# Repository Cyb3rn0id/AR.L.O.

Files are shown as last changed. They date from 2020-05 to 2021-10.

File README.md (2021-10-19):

This Repository is Archived since has been Replaced by the updated project [ARLOK](https://www.github.com/settorezero/arlok)

  

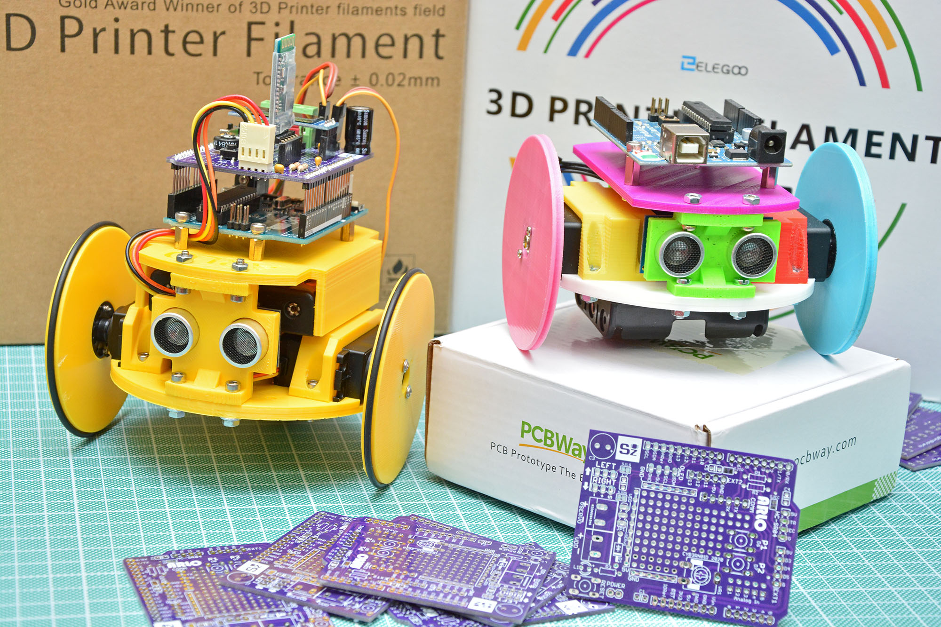
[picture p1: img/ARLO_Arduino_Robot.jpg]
ARLO - Arduino 3D printed Robot
  

# AR.L.O.
AR.L.O. Stands for ARduino Loaded with O-rings! It's an educational Arduino-based robot with a chassis printed in 3D. It features an ultrasonic range finder SR-HC04, an 0.91" OLED display, an HC-05 or HC-06 Bluetooth Module and two modified Servos (MG996R) for moving around.  I provided full-assembly instructions on my blog (see link at the end of this readme). Here you can find the STL to be printed and a source code.  Source code uses interrupts for make robot movement more efficient.

### PCBs by PCBWay
You can support my work by subscribing to PCBWay [using my invite link](https://www.pcbway.com/setinvite.aspx?inviteid=355653&from=settorezero2020) and then making AR.L.O. PCBs on PCBWay:   
PCB from PCBWay (https://www.pcbway.com/project/shareproject/ARLO___Arduino_3D_printed_Robot.html?from=settorezero2020)

### Links
- [Full Instructions](https://www.settorezero.com/wordpress/arlo)
- [BOM (Google Spreadheet with links)](https://docs.google.com/spreadsheets/d/1MPQHllO7yKMDYPbDrZOl-8qmw7OP9y3tJf0Bnw-yMyg/)
- [AR.L.O. video teaser](https://www.youtube.com/watch?v=O_3CUWvaW3k)
- [Video about AR.L.O. (only for italian users)](https://www.youtube.com/watch?v=JS_QYEIMfNo)
- [Video showing AR.L.O. setup](https://youtu.be/i7roltk-IzI)
- [AR.L.O. parts on Thingiverse](https://www.thingiverse.com/thing:4484651)
- [Servo Wheel by Obijuan](https://www.thingiverse.com/thing:19940)
- [Support my work by subscribing to PCBWay using my invite link](https://www.pcbway.com/setinvite.aspx?inviteid=355653&from=settorezero2020)
- [Support my work buying parts on Futura Elettronica after you've clicked on this link](https://www.futurashop.it/?tracking=5f004a6ba8be7)

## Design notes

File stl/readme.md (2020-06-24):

STL files for 3D printing.  
I've designed parts using [Tinkercad](https://www.tinkercad.com/).  

### Plate Base
I've added two plate bases which have different cavity for the servo: one large 40.6mm and the other large 41.2mm. Normally, standard servos are large 40mm, so the first one, 40.6mm. is suitable for servos like the Hi-tech that respect measures (consider also tolerances from 3D-Printer). I've found that some other servos, such as the XQPower I use, are slightly larger (about 40.8mm) and can't fit in the previous cavity, so I made a new cavity of 41.2mm and now the XQPower ones fits perfectly. So measure your servo width first than print. In case of doubt, print the 41.2mm.
  
### Wheels  
Wheels are generated with [Openscad](https://www.openscad.org/) using [Obijuan script](https://www.thingiverse.com/thing:19940) "Servo Wheel" on Thingiverse. You can found the script also on his [Github Repo for Miniskybot](https://github.com/Obijuan/Miniskybot/)

### Models
Arduino model, used for sizing and holes, is from [cmspooner on Thingiverse](https://www.openscad.org/)

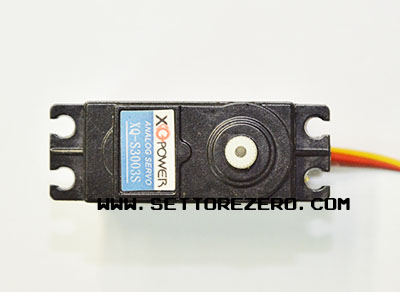
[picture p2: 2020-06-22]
img/arlo_servomotor.jpg

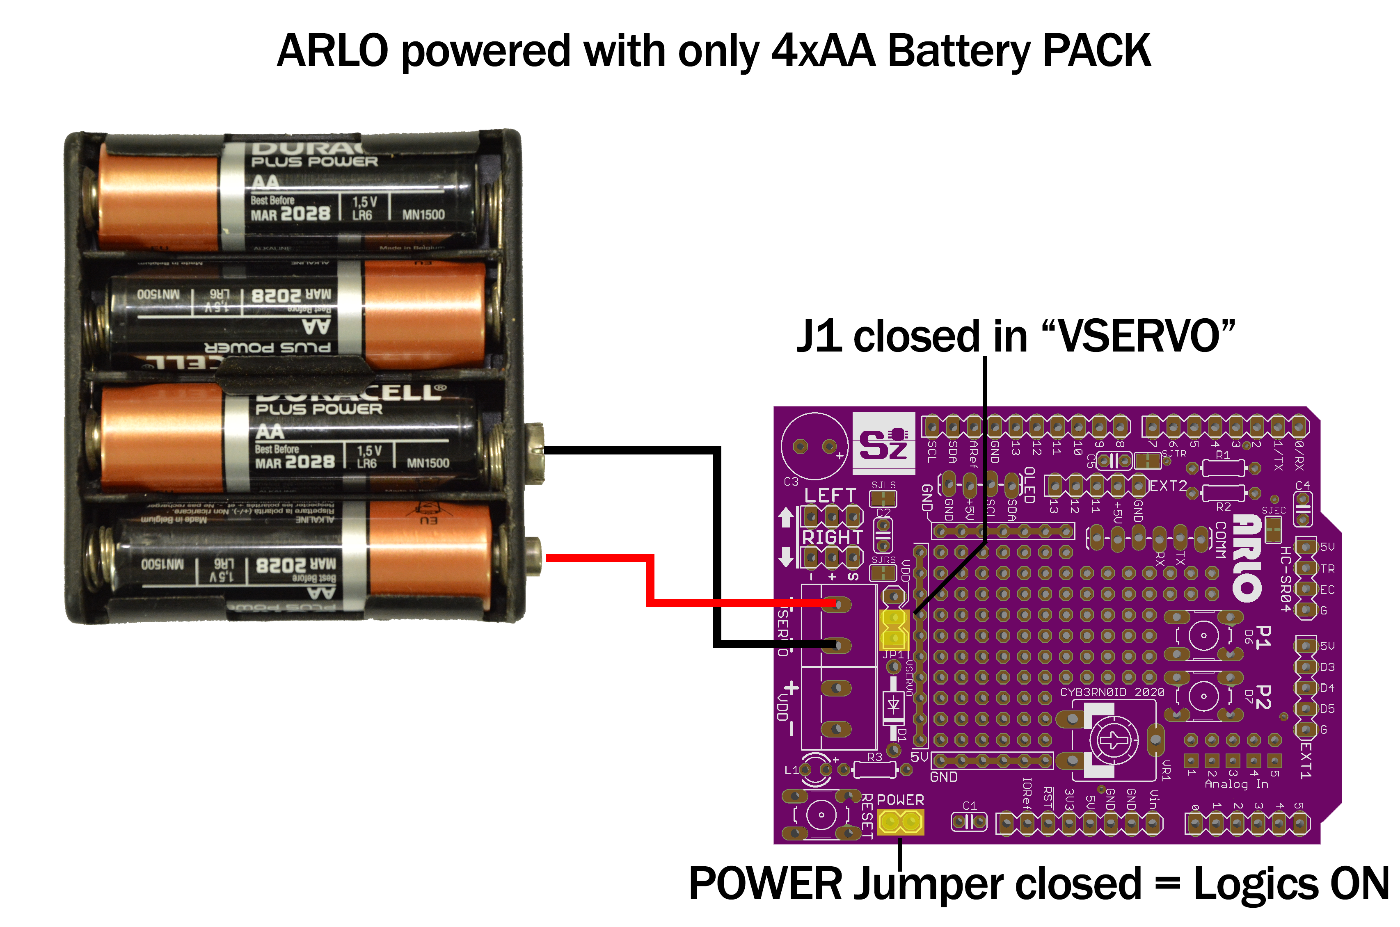
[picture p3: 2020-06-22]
img/arlo_shield_power_only6V.png

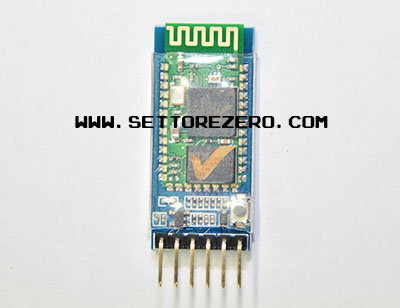
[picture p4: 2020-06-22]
img/arlo_bluetooth_module.jpg

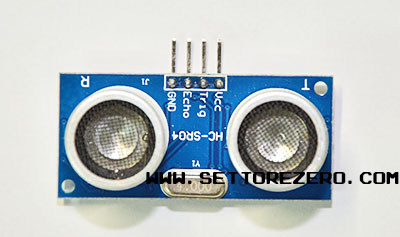
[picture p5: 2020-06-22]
img/arlo_ultrasonic_sensor.jpg

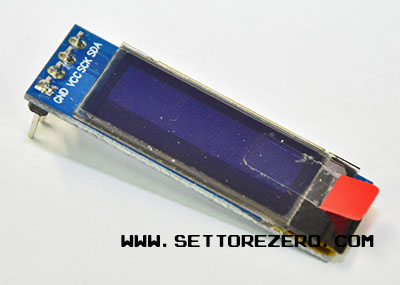
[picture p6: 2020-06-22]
img/arlo_oled_display.jpg

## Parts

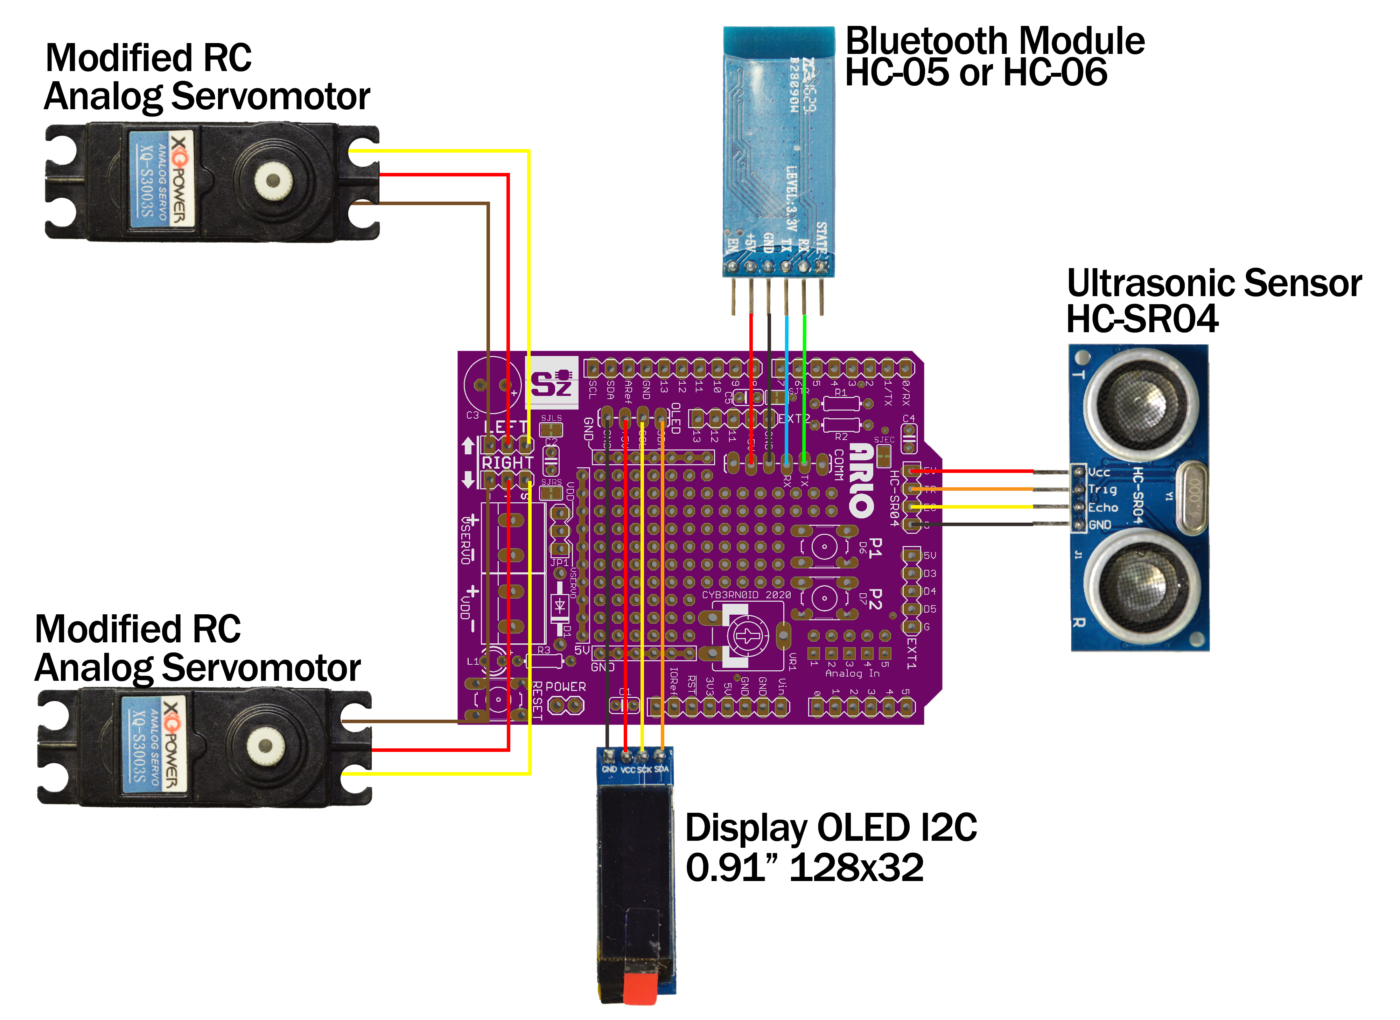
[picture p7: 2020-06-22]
img/arlo_shield_external_components.png

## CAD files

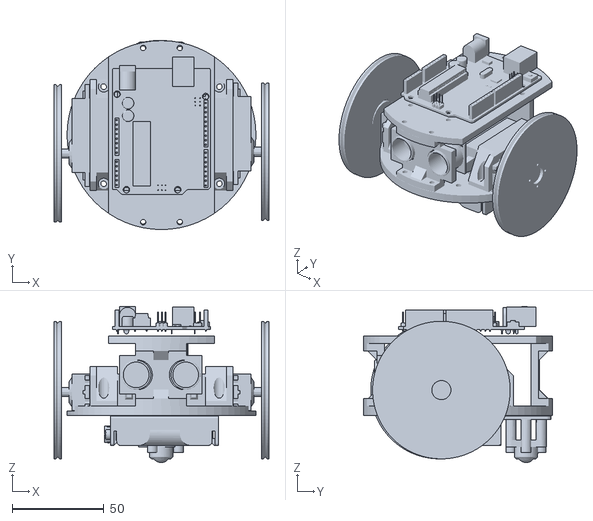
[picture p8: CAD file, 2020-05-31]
img/arlecchino_assembly.stl
117.2 x 103.1 x 85.1

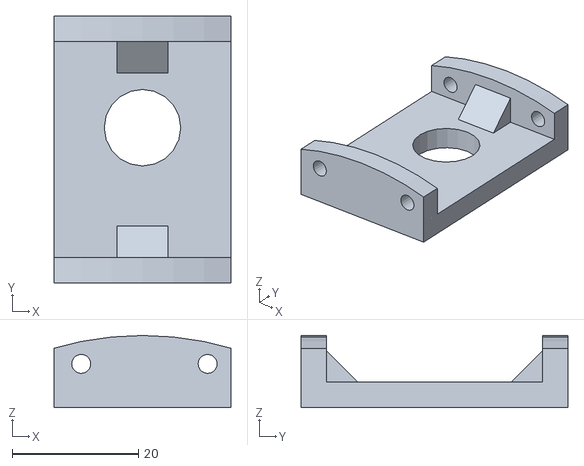
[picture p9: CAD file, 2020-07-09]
stl/pillar_hole_12mm.stl
28.0 x 42.2 x 11.4

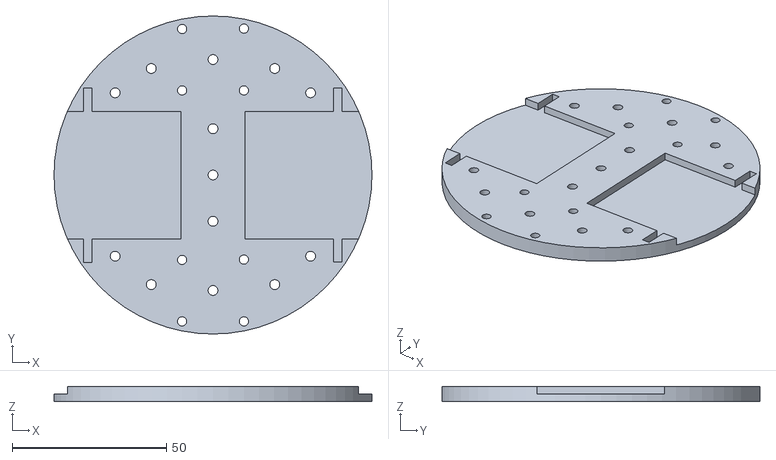
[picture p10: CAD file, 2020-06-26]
stl/plate_base.stl
103.0 x 103.0 x 5.00

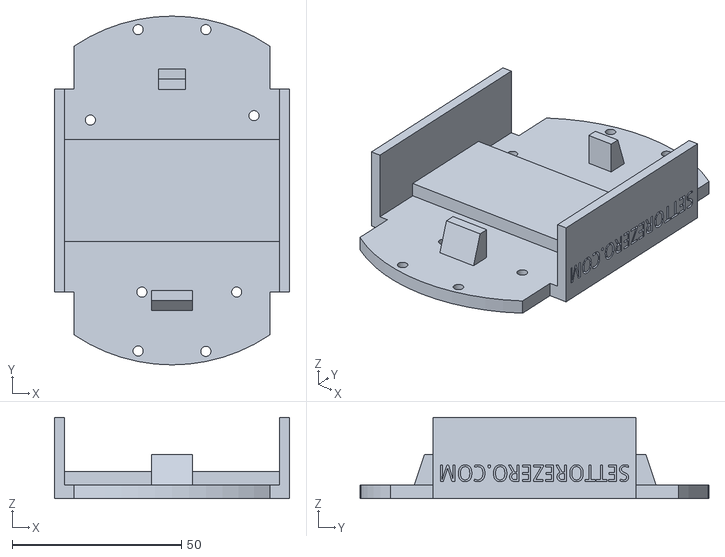
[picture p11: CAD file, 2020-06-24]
stl/plate_top.stl
69.4 x 103.0 x 24.0

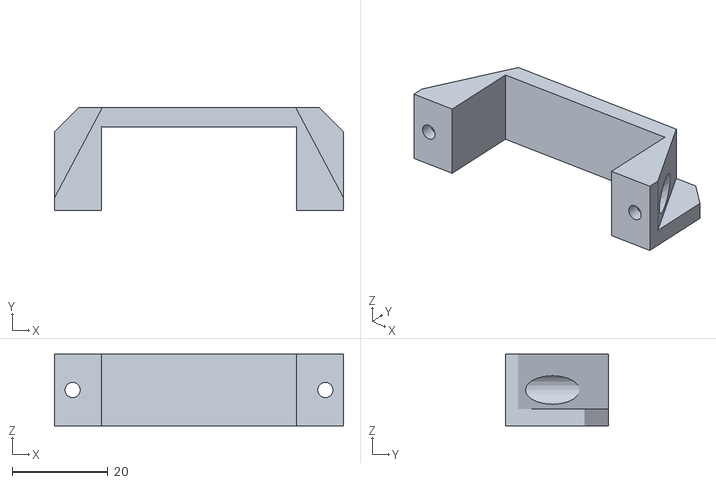
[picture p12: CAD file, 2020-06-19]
stl/servo_bracket.stl
60.5 x 21.5 x 15.0

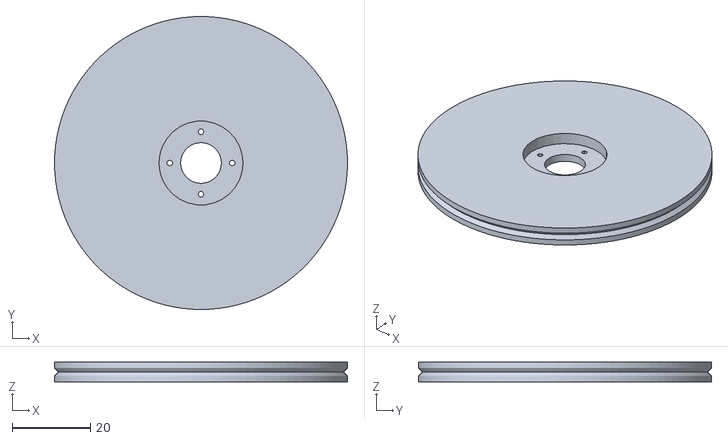
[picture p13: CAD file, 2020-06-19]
stl/my_servo-wheel.stl
75.0 x 75.0 x 5.00

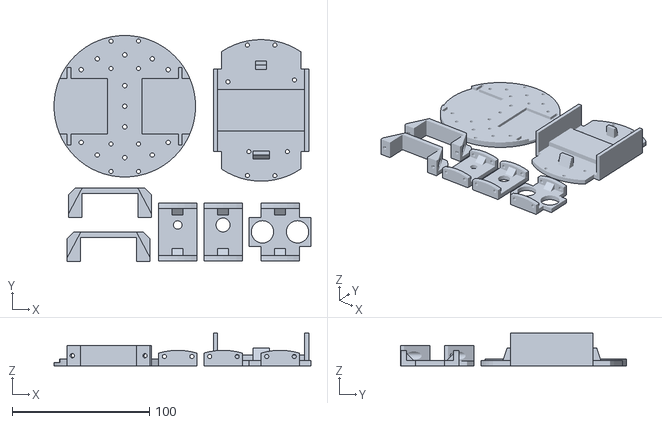
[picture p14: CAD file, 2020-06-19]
stl/all_but_wheels.stl
187.0 x 164.5 x 24.0

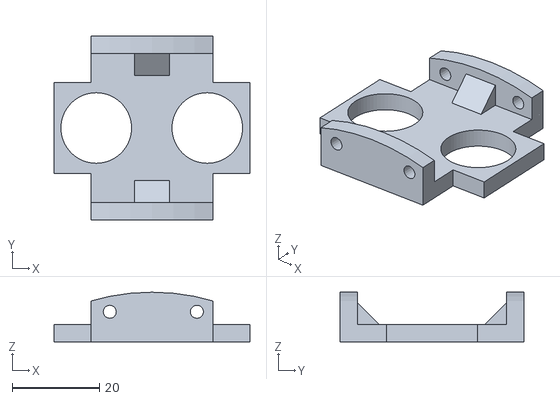
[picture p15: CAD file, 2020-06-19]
stl/pillar_HC-SR04.stl
45.0 x 42.2 x 11.4

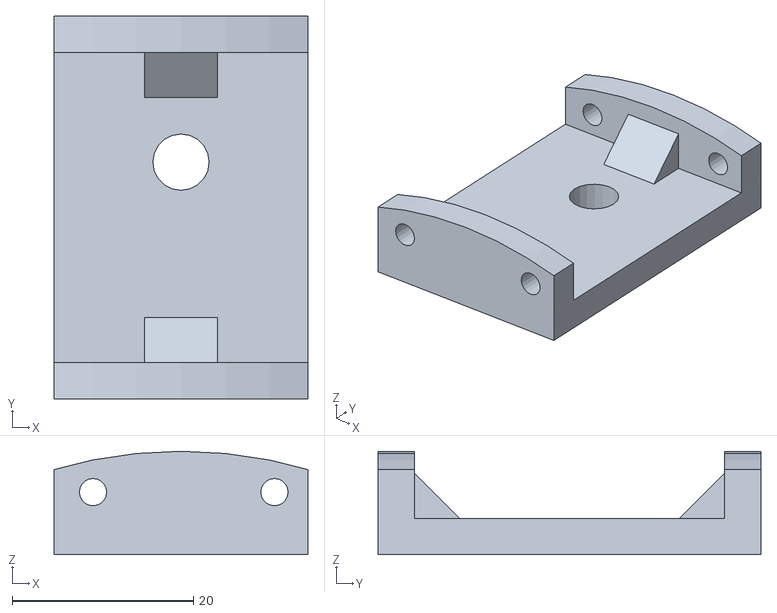
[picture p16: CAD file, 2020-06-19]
stl/pillar_hole_6mm.stl
28.0 x 42.2 x 11.4

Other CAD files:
stl/pillar_hole_10mm.stl

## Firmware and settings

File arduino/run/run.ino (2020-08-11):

/*
 * AR.L.O.
 * ARduino Loaded with Orings!
 * Educational Robot based on Arduino UNO
 * (c)2020 Giovanni Bernardo (https://www.settorezero.com)
 * 
 * https://www.github.com/CyB3rn0id/ar.l.o.
 * https://www.settorezero.com/wordpress/arlo
 * 
 * WARNING
 * This example will not work on Arduino LEONARDO
 * since it hasn't the Timer2
 *
 * LICENSE
 * Attribution-NonCommercial-ShareAlike 4.0 International 
 * (CC BY-NC-SA 4.0)
 * 
 * This is a human-readable summary of (and not a substitute for) the license:
 * You are free to:
 * 
 * SHARE - copy and redistribute the material in any medium or format
 * ADAPT -  remix, transform, and build upon the material
 * The licensor cannot revoke these freedoms as long as you follow the license terms.
 * Under the following terms:
 * ATTRIBUTION -  You must give appropriate credit, provide a link to the license, 
 * and indicate if changes were made. You may do so in any reasonable manner, 
 * but not in any way that suggests the licensor endorses you or your use.
 * NON COMMERCIAL -  You may not use the material for commercial purposes.
 * SHARE ALIKE -  If you remix, transform, or build upon the material,
 * you must distribute your contributions under the same license as the original.
 * NO ADDITIONAL RESTRICTIONS - You may not apply legal terms or technological 
 * measures that legally restrict others from doing anything the license permits.
 * 
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
 * Please read the Full License text at the following link:
 * https://creativecommons.org/licenses/by-nc-sa/4.0/legalcode
 *  
 * CREDITS
 * 
 * Steve Garrat
 * For the idea about using HC-SR04 sonar on interrupts:
 * (https://homediyelectronics.com/projects/arduino/arduinoprogramminghcsr04withinterrupts/)
 * 
 * Nick Bontranger
 * For the library allows using servo on Timer 2
 * https://github.com/nabontra/ServoTimer2
 * 
 * Adafruit
 * Because makes a lot of useful libraries
 * 
 * LIBRARIES TO BE INSTALLED
 * 
 * - Adafruit SSD1306 by Adafruit
 * - Adafruit GFX by Adafruit
 * - TimerOne by Jesse Tane, Jérôme Despatis, Michael Polli, Dan Clemens, Paul Stoffregen
 * 
 * This one requires manual installation (copy the folder in Documents\Arduino\Libraries)
 * https://github.com/nabontra/ServoTimer2
 * 
 */

// Libraries for OLED display
#include <SPI.h>
#include <Wire.h>
#include <Adafruit_GFX.h>
#include <Adafruit_SSD1306.h>
// Library for Timer1 Interrupts
#include <TimerOne.h>
// Library for using servo on Timer 2
#include <ServoTimer2.h>
// Library for Arduino internal eeprom memory
#include <EEPROM.h>

// Arduino used pins
#define MotorRPin 9       // signal for right servomotor
#define MotorLPin 10      // signal for left servomotor
#define P1 6              // pushbutton P1
#define P2 7              // pushbutton P2
#define trigPin 8         // HC-SR04 - trigger
#define echoPin 2         // HC-SR04 - echo

// stuff used by servomotors
ServoTimer2 MotorL;       // left servomotor object
ServoTimer2 MotorR;       // right servomotor object
uint16_t servoL_center=1500; // default value for left servomotor center point
uint16_t servoR_center=1500; // default value for right servomotor center point
uint8_t servoL_eeprom=0; // eeprom memory location for storing point zero of left servomotor
uint8_t servoR_eeprom=2; // eeprom memory location for storing point zero of right servomotor
#define SPEED  200 // normal speed for forward moving (center point+speed microseconds)
#define SPEED_SLOW 50 // speed used for maneuvers

// stuff used by sonar
#define TIMER_US 50 // Timer1 interrupt every 50uS
#define TICK_COUNTS 4500 // 4500*50uS = 225mS, time space between two consecutive trigger pulses
#define OBSTACLE 16 // AR.L.O. will stop if an obstacle is nearer than 16cm

// stuff used by oled display
#define SCREEN_WIDTH 128
#define SCREEN_HEIGHT 32
#define OLED_RESET -1
Adafruit_SSD1306 display(SCREEN_WIDTH, SCREEN_HEIGHT, &Wire, OLED_RESET);

// Global variables
volatile long distance=0; // distance measured by sonar, cm
// enum used for AR.L.O. working mode
enum arlo_mode
  {
  configuration,
  normal  
  };
arlo_mode mode=normal;// actual mode
// enum used for config menu pages on display
enum config_pages
  {
  left_motor=0,
  right_motor=1,
  config_end=2  
  };
  
void setup() 
  {
  // sonar setup
  pinMode(trigPin, OUTPUT);
  pinMode(echoPin, INPUT);
  // servomotors setup
  MotorL.attach(MotorLPin);   
  MotorR.attach(MotorRPin);
  // pushbuttons setup
  pinMode(P1,INPUT_PULLUP);
  pinMode(P2,INPUT_PULLUP);

  // interrupts
  Timer1.initialize(TIMER_US); // Initialise timer 1
  Timer1.attachInterrupt(timer1_ISR); // Attach interrupt to the timer service routine 
  attachInterrupt(digitalPinToInterrupt(echoPin), sonarEcho_ISR, CHANGE); // Attach interrupt to the sensor echo input
  
  delay(2000);
  Serial.begin(9600); // the HC-05 in normal mode (no AT) works ad 9600baud (38400 if in AT)
  
  randomSeed(analogRead(3)); // start-up random number generator using an unused analog input

  // SSD1306_SWITCHCAPVCC = generate display voltage from 3.3V internally
  if(!display.begin(SSD1306_SWITCHCAPVCC, 0x3C)) 
    { // Address 0x3C for 128x32
    Serial.println(F("SSD1306 allocation failed"));
    while(1); // Don't proceed, loop forever
    }
  display.clearDisplay();
  display.setTextSize(2);
  display.setTextColor(SSD1306_WHITE,SSD1306_BLACK);

  Serial.println("ARLO Startup");
  
  // center values used for servomotors, loaded from eeprom
  // if in the eeprom are saved values out of the range 500-2500, 1500 will be used
  // (this happens when eeprom memory was never used since contains 0xFFFF value)
  uint16_t LV=EEPROM.read(servoL_eeprom)<<8;
  LV|=EEPROM.read(servoL_eeprom+1);
  uint16_t RV=EEPROM.read(servoR_eeprom)<<8;
  RV|=EEPROM.read(servoR_eeprom+1);
  if (LV<2501 && LV>499) servoL_center=LV;
  if (RV<2501 && RV>499) servoR_center=RV;

  fermo(100);
  
  // if P1 is pressed during the setup function, I'll start the setup mode
  if (digitalRead(P1)==0) 
    {
      mode=configuration;
      while(digitalRead(P1)==0) {continue;}
      Serial.println("Setup mode");
    }
  }

void loop()
  {
  static boolean juststarted=true;
  while (mode==configuration) config_menu();

  display.setTextSize(2);
  display.setCursor(0,0);
  
  if (juststarted)
    {
    fermo(100);
    display.println("WAIT");
    display.display(); 
    fermo(2000); // servomotors stopped while sonar goes stable
    juststarted=false;  
    }
  display.println("ARLO RUN");
  if (distance>3000)
    {
    display.print("go ahead!");
    }
  else
    {
    display.print(distance);
    display.print("cm       ");
    }
  display.display();  

  // distance is greater than obstacle
  if(distance>OBSTACLE)
    {
    dritto(SPEED);
    }
  else
    {
    uint8_t randomNum=random(0,1);
    Serial.println("stop");
    // deceleration
    dritto(SPEED-50);
    delay(100);
    dritto(SPEED-100);
    delay(100);
    dritto(SPEED-150);
    delay(100);
    // stop
    fermo(100);
    indietro(1000);
    fermo(100);
    if (randomNum)
        {
        destra(1000);
        }
    else
        {
        sinistra(1000);
        }
    fermo(100);
    }
  }

void config_menu(void)
  {
  static config_pages actual_page=0;
  static bool splash=true;

  if (splash)
    {
    display.setCursor(0,0);
    display.println("ARLO SETUP");
    display.display();  
    delay(2000);
    display.clearDisplay();
    display.setCursor(0,0);
    display.display(); 
    splash=false;
    delay(1000);
    }
  
  uint16_t val=analogRead(0);
  // mapping 0-1023 a 500-2500
  uint16_t pos=map(val, 0, 1023, 500, 2500);
  
  switch(actual_page)
    {
    case left_motor: // left servomotor setup
      display.setCursor(0,0);
      display.setTextSize(1);
      display.print("LEFT MOTOR (");
      display.print(servoL_center);
      display.println(")");
      display.setTextSize(2);
      display.print(pos);
      display.print("  ");
      display.println();
      display.setTextSize(1);
      display.print("P1: save P2: next");
      display.display();  
      MotorL.write(pos);
    break;

    case right_motor: // right servomotor setup
      display.setCursor(0,0);
      display.setTextSize(1);
      display.print("RIGHT MOTOR (");
      display.print(servoR_center);
      display.println(")");
      display.setTextSize(2);
      display.print(pos);
      display.print("  ");
      display.println();
      display.setTextSize(1);
      display.print("P1: save P2: next");
      display.display();  
      MotorR.write(pos);
    break;

    case config_end:
      display.setTextSize(2);
      display.setCursor(0,0);
      display.println("P1: Exit");
      display.println("P2: Return to Setup");
      display.display();
      break;
    } // switch

  // P1 pressed: confirm value or exit from menu
  if (digitalRead(P1)==0)
    {
    delay(50);
    if(digitalRead(P1)==0)
      {
      while(digitalRead(P1)==0) {continue;}
      switch(actual_page)
        {
          case 0:
            servoL_center=pos;
            // I must split the 16bit value in two bytes
            // and save values in 2 different EEPROM locations
            EEPROM.update(servoL_eeprom, (uint8_t)(pos>>8));
            delay(4); // an eeprom.write takes 3.3mS
            EEPROM.update(servoL_eeprom+1, (uint8_t)(pos&0x00FF));
            delay(4);
            Serial.print("Left zero: ");
            Serial.println(pos);
            break;

          case 1:
            servoR_center=pos;
            // I must split the 16bit value in two bytes
            // and save values in 2 different EEPROM locations
            EEPROM.update(servoR_eeprom, (uint8_t)(pos>>8));
            delay(4); // an eeprom.write takes 3.3mS
            EEPROM.update(servoR_eeprom+1, (uint8_t)(pos&0x00FF));
            delay(4);
            Serial.print("Right zero: ");
            Serial.println(pos);
            break;

          case 2:
            // exit from menu
            mode=normal;
            display.clearDisplay();
            display.display();
            Serial.println("Config exit");
            return;
            break;
        }
      }
    }

  // P2 pressed: change the page
  if (digitalRead(P2)==0)
    {
    delay(50);
    if(digitalRead(P2)==0)
      {
      while(digitalRead(P2)==0) {continue;}
      // the C++ deals with enums as an independent type
      // so we must convert it in an integer if we want to use the ++ operator
      uint8_t tmp=(uint8_t)actual_page;
      tmp++;
      if (tmp>(uint8_t)config_end) tmp=0;
      actual_page=(config_pages)tmp;
      
      display.clearDisplay();
      display.display();
      delay(10);
      }
    }
  }

  
// moves forward at 'vel' speed
void dritto(uint16_t vel)
  {
  if (vel>SPEED) vel=SPEED;
  MotorL.write(servoL_center+vel);
  MotorR.write(servoR_center-vel);
  }

// moves backward at slow speed for ms milliseconds
void indietro(long ms)
  {
  long timenow=millis();
  while((millis()-timenow)<ms)
    {
    MotorL.write(servoL_center-SPEED_SLOW);
    MotorR.write(servoR_center+SPEED_SLOW);
    }
  }

// turns right at slow speed for ms milliseconds
void destra(long ms)
  {
  long timenow=millis();
  while((millis()-timenow)<ms)
    {
    MotorL.write(servoL_center+SPEED_SLOW);
    MotorR.write(servoR_center+SPEED_SLOW);
    }
  }

// turns left at slow speed for ms milliseconds
void sinistra(long ms)
  {
  long timenow=millis();
  while((millis()-timenow)<ms)
    {
    MotorL.write(servoL_center-SPEED_SLOW);
    MotorR.write(servoR_center-SPEED_SLOW);
    }
  }

// Servomotors stopped
void fermo(long ms)
  {
  long timenow=millis();
  while((millis()-timenow)<ms)
    {
    MotorL.write(servoL_center);
    MotorR.write(servoR_center);
    }
  }
  
// Timer1 every 50uS : sends the pulse signal
void timer1_ISR()
  {
  static volatile int state=0; // actual state of pulse signal
  static volatile int trigger_time_count=0; // countdown used to re-triggering
  
  if (!(--trigger_time_count)) // counting up to 225mS (defined by TICK_COUNTS)
    {
    trigger_time_count=TICK_COUNTS; // reload the counter
    state=1; // we're ready to retrigger
    }
    
  switch(state)
    {
    case 0: // does nothin: I'll wait the 225ms
      break;

    case 1:  // send the pulse signal
      digitalWrite(trigPin, HIGH);  // trigger pin at high level
      state=2; // go to the next step, see you in 50uS
      break;
        
    case 2: // stop the pulse signal
    default:      
      digitalWrite(trigPin, LOW); // trigger pin at low level
      state=0; // do nothing, see you in 225mS
      break;
    }
  }

// interrupt on state change of echo pin
void sonarEcho_ISR()
  {
  static long echo_start=0; // time at which echo high pulse is arrived
  static long echo_end=0; // time at which echo low pulse is arrived
  long echo_duration=0; // echo lasting in microseconds
  switch (digitalRead(echoPin)) // check echo pin if is high or low
    {
    case HIGH: // echo is just started
      echo_end=0;
      echo_start=micros(); // save starting time
      break;
      
    case LOW: // echo is finished
      echo_end=micros(); // save ending time
      if (echo_end>echo_start) // I check that there is no micros() overflow
        {
        echo_duration=echo_end-echo_start; // decho lasting, in microseconds
        distance=echo_duration/58; // distance in cm, global variable
        }
      break;
    }
  }
  

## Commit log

2020-05-24 uploaded Rainbowt 3D design files
    [all_but_wheels.stl, my_servo-wheel.stl, pillar.stl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]
2020-05-31 Measures updated
    - plate base slightly larger (+2mm) so the Tamiya 70144 ballcaster fit perfectly with a 3xAA battery holder mounted on bottom plate
    - plate base modified for accepting standard RC servos
    - pillars height increased
    - 2 pillars added: hole 6mm for lever switches, 10mm for pushbutton switchtes - choose the one you like for mounting a switch
    - corrected measures for HCSR05 servo
    - servo bracket shape changed: only 2 holes on the base and small holes for servo mounting
    - top plate 2mm larger as the base
    [pillar_HC-SR05.stl, pillar_hole_10mm.stl, pillar_hole_6mm.stl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]
2020-05-31 it's HC-SR04
    [pillar_HC-SR04.stl]
2020-06-19 ARLO definitive 3D parts
    [all_but_wheels.stl, my_servo-wheel.stl, pillar_HC-SR04.stl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]
2020-06-24 2 cavity dimensions for different servo models
    [plate_base_(40.60_servo_cavity).stl, plate_base_(41.20_servo_cavity).stl]
2020-06-24 2 different servo cavity, with text
    [plate_base_(40.6_servo_cavity).stl, plate_base_(41.2_servo_cavity).stl]
2020-06-24 added site writing on a side
    [plate_top.stl]
2020-06-25 enlarged cavity depth by 1mm
    [plate_base_(40.6_servo_cavity).stl, plate_base_(41.2_servo_cavity).stl]
2020-06-25 servo cavity at 39.5mm depth
    [plate_base_(40.6_servo_cavity).stl, plate_base_(41.2_servo_cavity).stl]
2020-06-26 one size fits all
    [plate_base_(41.2_servo_cavity).stl]
2020-06-29 added warning for arduino leonardo
2020-07-09 added pillar hole 12mm
    [pillar_hole_12mm.stl]

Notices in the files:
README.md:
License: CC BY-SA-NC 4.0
